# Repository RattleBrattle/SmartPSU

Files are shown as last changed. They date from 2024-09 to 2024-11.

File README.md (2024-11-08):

# SmartPSU

Welcome to the Smart Power Supply project! This repository contains the code and design files for a versatile power supply unit currently under development. The smart power supply is designed to provide reliable and adjustable power output for various applications, featuring multiple modes to cater to different power requirements.

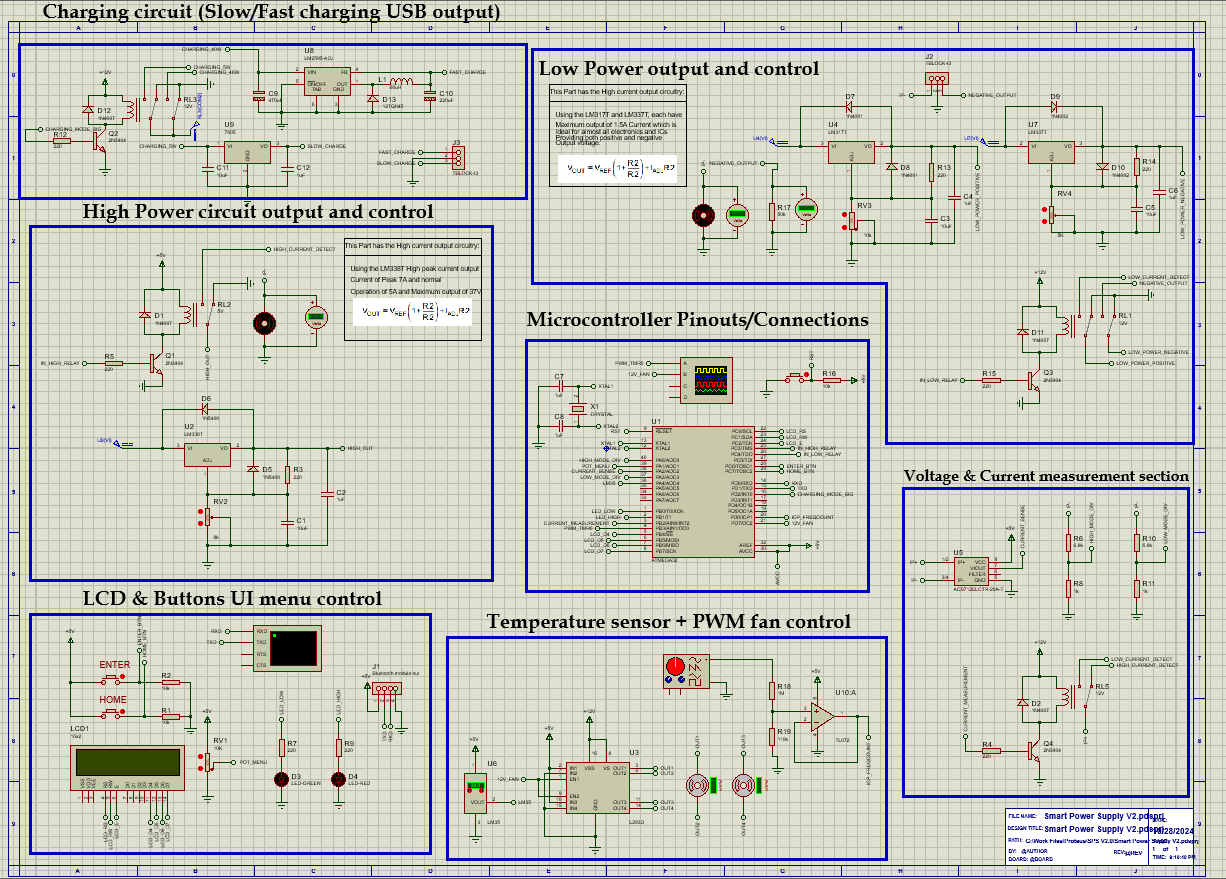
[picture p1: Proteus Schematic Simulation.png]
This Picture is a final representation of the Smart Power Supply circuit and is simulation for Proteus


## Features

The Smart Power Supply has 5 main features:
- The voltage is sensed using a voltage divider of Power Resistors.
- The Current is measured using the current sensor module board ACS712.

## Components:
* ACS712 Current sensor module board 20A.
* Linear Transformer 24V @ 5A.
* 4x 18650 battery holder.
* TP4056 Lithium battery charger.
* 120mm Fan.
* L7812, L7805 Regulators and their dependencies.
* LM317T and LM337T for Low power circuit and it's dependencies.
* LM338T for High Power circuit and it's dependencies.
* L293D for PWM fan control.
* LM35DZ Temperature sensor.
* LCD 16x2 display.
* 10kohm potentiometer, two buttons for the Menu controls.
* 2 USB type A female outputs for charging circuits output.
* 8 Banana Plugs for outputs of Power circuits and input of Frequency counter.

### High Power Mode:
- The mode's output is maximum at 5A, and at around 34V that means the output is around ~170W!
- Provides a high power output suitable for demanding applications and High Powered electronics.
- Ensures stable and efficient power delivery for high-performance devices using the effective but simple LM338T voltage regulator.

### Low Power Mode:
- This mode's output is maximum at 1.5, which is suitable for everyday electronics and logic circuits or weak motors.
- Offers a low power output for energy-efficient operation.
- Ideal for applications that require minimal power consumption.
- both positive and negative output using the LM317T and LM337T voltage regulators respectively.
- 
### Charging Circuits:
- 5W circuit and a 40W circuit for both USB output ports.
- Includes dedicated charging circuits for various battery types and Charging mobile phones.
- Supports charging for 18650 and Lithium-ion batteries.
- Ensures safe and efficient battery charging with built-in protection features.

40W Charging Circuit schematic:
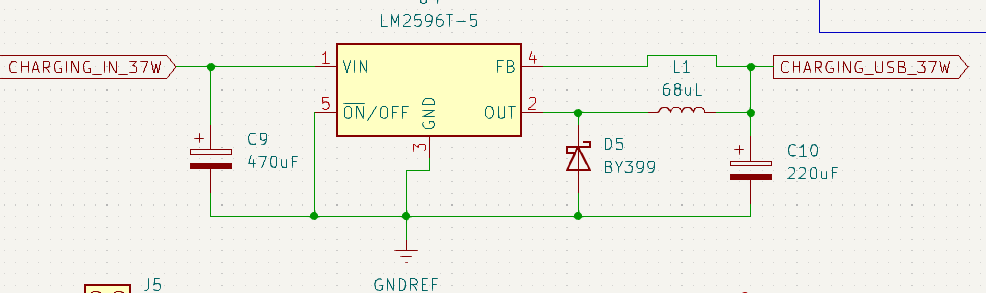
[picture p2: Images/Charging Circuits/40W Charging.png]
40W Charging Circuit


30W Charging Circuit schematic:
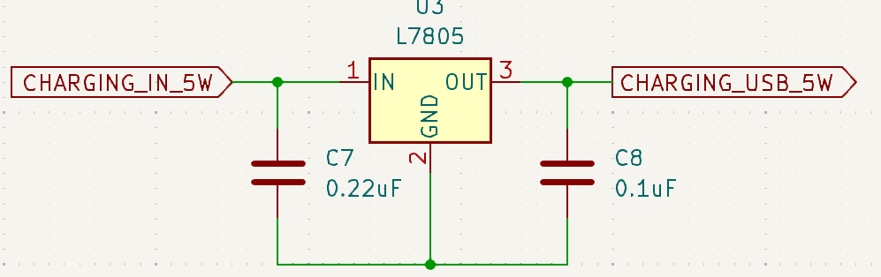
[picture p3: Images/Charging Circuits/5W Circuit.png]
30W Charging Circuit


### Frequency Counter:
- Using Precise calculations and the Timer 1 Peripheral on the ATmega32A, i managed to code a very useful feature
like that in the Smart Power Supply, simply put the frequency counter gives the user option to choose between the diverse
type of Prescalers in the ATmega32A Timer 1 peripheral depending on the frequency of the signal being tested.
The user Changes the Prescaler just like the main menu using the potentiometer and buttons.

- Example of the Menu:
Prescaler-Menu

### PWM Fan Control and Temperature sensor:
- The user can control the FAN speed by choosing the option in the Main Menu, using the L293D
as PWM controller and the Input power is 12V using the L7812 Regulator.
- The Power supply also has a critical function, a function that calculates the current temperature.
Where if the current temperature exceeds 35 degrees, Their is a warning message that is prompted to the user
on the LCD screen warning them!

The Temperature sensor and 12V fan Control:

## 3D Case model:
- I've modeled a 3D case for the Device using Fusion 360, the case is ready to be 3D printed as i've also uploaded the 3D files
above.

3D case Front:

3D case Back:

### Usage
When the user first powers on the device, the LCD screen prints out a menu with a cursor.
- The user controls the cursor position by moving the Main Menu potentiometer next to the LCD screen.
- When the user wants the function chosen, Press the "ENTR" button.
- When the user wants to exit the current function, Press the "HOME" button.

## Contributing

Contributions are welcome! If you have any suggestions, bug reports, or feature requests, Please email me at baselmohamed802@gmail.com or [message me on my LinkedIn page](www.linkedin.com/in/basel-sayed-b11534243) ! 

## License

This project is licensed under the [GNU] - see the [LICENSE](LICENSE) file for details.

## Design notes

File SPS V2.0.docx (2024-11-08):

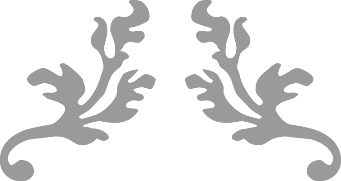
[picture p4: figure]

Smart power supply v2.0

A Smart power supply using ATmega32A Microcontroller capable of just about anything.

September 18, 2024

Basel Mohamed Mostafa Sayed

# SPS v2.0 details:

1) 120W+ Linear Power Supply.
2) Has two charging ports, one for normal speeds (5W) and the other for high-speed charging (37W).
- The 5W charging circuit will be current limited to 1A using the L7805 regulator.
- The 37W charging circuit will be using the LM2596 step-down voltage regulator.
3) Has two output voltage modes,
- The first is a positive only High ampere output capable of delivering full power at 7A peak.
- Using the LM338T voltage regulator
- The second is a positive AND negative medium (1.5A) output capable of everyday electronic testing.
- Using LM317T and LM337T for both positive and negative voltages respectively.
4) Has a charging port for 18650 batteries.
5) Has a charging port for Lithium-ion batteries using the TP4056 battery charging module.
6) PWM fan control using the L293D motor driver as PWM controller and Fan motor connection, and 12V regulator L7812 and IRF540N.

All of this will be controlled using the ATmega32A microcontroller.

- All the outputs will be controlled via relays or high power MOSFETS, each output will be a function that YOU (The user) execute via a menu that appears on the LCD.
- Voltage reading will be via voltage dividers.

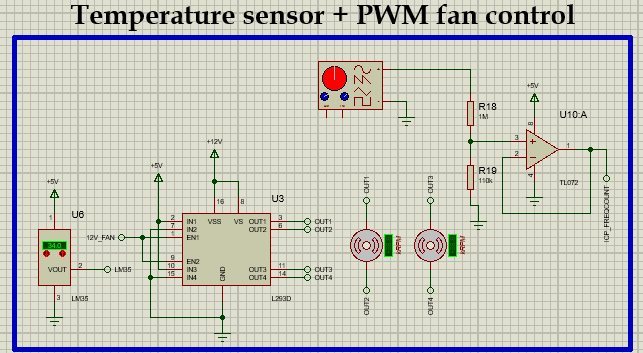
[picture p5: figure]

- Current reading will be using the ACS712 current sensor module (up to 20A).

## Explaining each function with detail:

In this section, I will explain to you each function that the SPS (Smart Power Supply) V2.0 is capable of and providing circuit schematic and connection explanations.

### 1) The main two outputs of the SPS v2.0:

→In here I will explain the main two outputs.

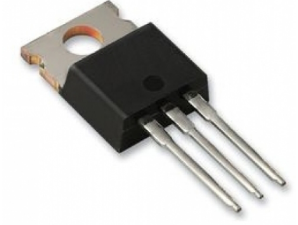
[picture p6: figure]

#### The first being the HIGH ampere output with full power.

→I will be using the LM338T, which is an excellent voltage regulator capable of delivering a MAX 5A load with 32V which will be more than enough to power most DC motors and high-powered components.

- Using the ATmega32’s PWM output (TMR0) as a driver for a MOSFET (NMOS) to efficiently and effectively control the output voltage.
- The MOSFET I am using is going to be IRLZ44N – NMOS, which for this use case is going to be more than sufficient in controlling the voltage output via PWM from the ATmega32A.

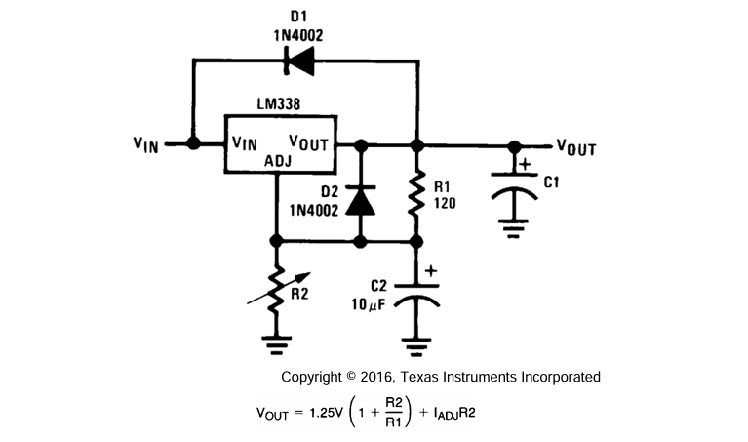
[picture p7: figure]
A diagram of a circuit

For the LM338T, we’re going to connect it using the figure given in the datasheet and since stated in the datasheet for outputs more than 24V we need protections diodes, so we’re going to use protection diodes.

For maximum output voltage which in the case of our smart power supply’s transformer

√2⋅24=33.9≈34V so, with this output in mind, we use the equation given by the datasheet to achieve maximum output.

34=1.25(1+(R_2)/220) So then R_2 =5984≈6kΩ .

So, for this configuration a variable resistor of 8K would do, but since there are no 8K potentiometer we can use the nearest value which would be 10K.

→Where the ATmega32A via user input using the menu on the LCD, sends a signal to the Relay controlling the output and sends it to the current sensor ACS712 and prints the voltage output and current measured on the LCD screen.

Here is the Final working simulation of the High-power output circuit:

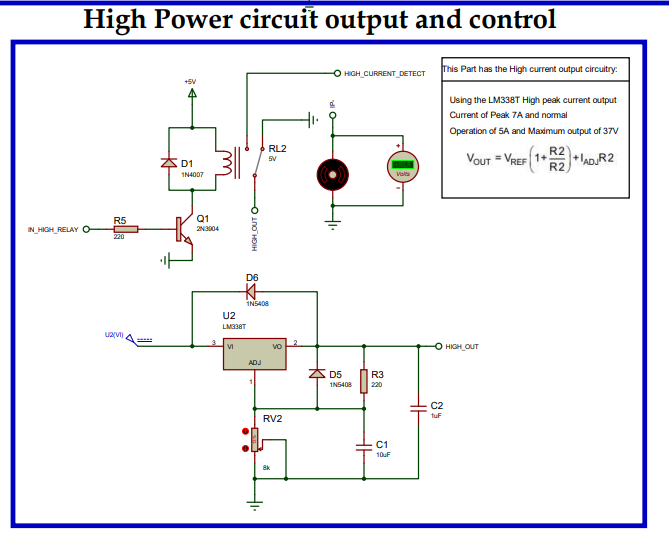
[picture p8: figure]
A diagram of a circuit
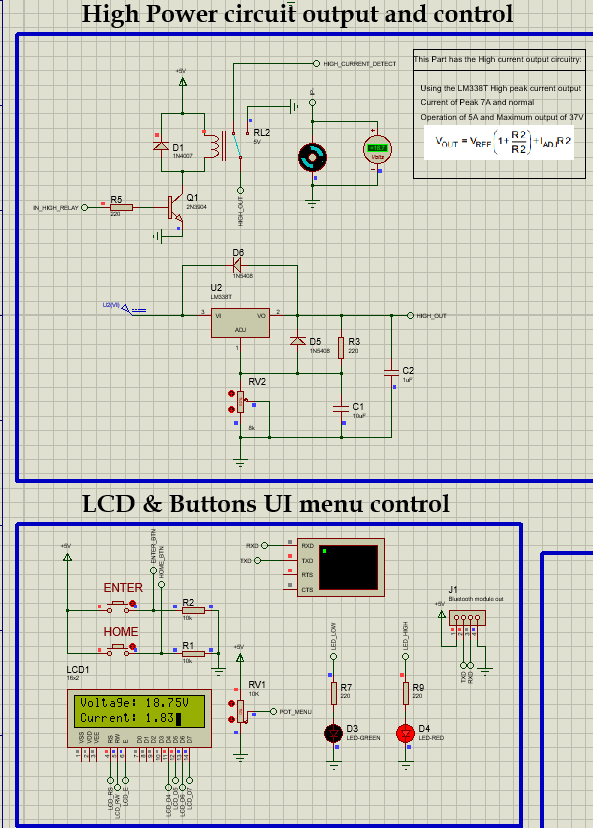
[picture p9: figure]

Here is the output voltage & current being measured by the ATmega32A and printed on the LCD screen:

#### The second being the Positive & Negative low output circuit:

→In this mode, I will stick to the tried and true positive and negative voltage regulators.

- The LM317T and the LM337T.
- Both offer the same Ampere output and will do greatly at just about testing everyday electronic components that don’t require much power unlike the LM338T.

Similarly, I am going to be using a PWM control signal to efficiently and effectively create a drive signal for the NMOS connected to the Low output.

Circuit for LM317T & LM337T:

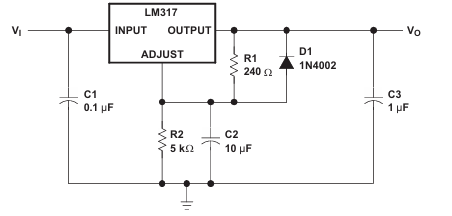
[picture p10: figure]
A diagram of a device

In this circuit, we have improved ripple rejection (increase signal output stability) by adding the capacitors at the input and C2 at the ADJ pin, similarly Diode D1 exists as protection in case the output is shorted to ground.

- The LM317T and LM337T follows the same formula as the LM338T so the circuit values are going to be the same as above and again, we will use the same 10K ohm potentiometer.

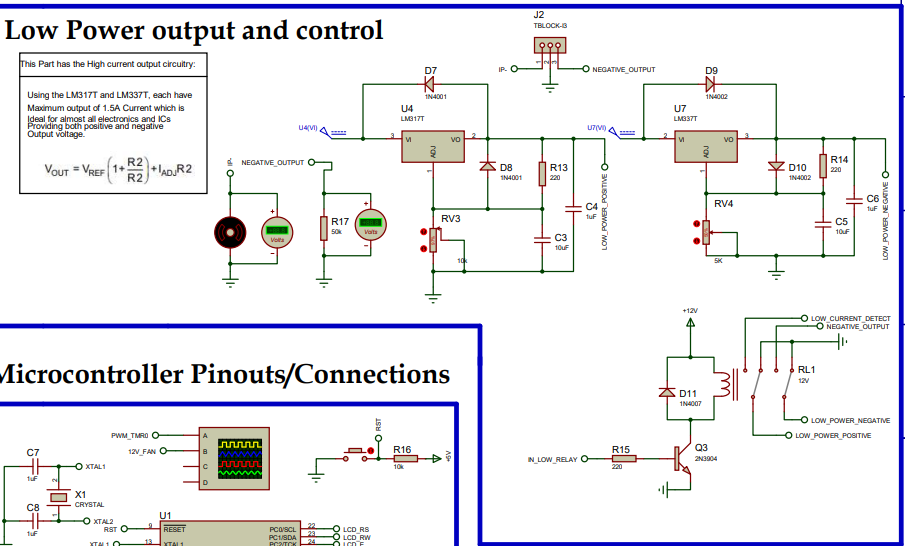
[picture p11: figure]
A diagram of a machine

→In the circuit above, we have the connections for the LM317T and LM337T with one signal that is controlled by the ATmega32A where once again like the High-power circuit, the voltage and current are measured and printed on the screen.

### 2) Charging circuits:

→The charging circuits for the USB output ports are simple enough to charge most phones and power most USB powered electronic devices.

To enable the Charging circuit outputs, the user chooses mode 3 in the LCD screen menu which sends a signal via the ATmega32A to the Relay controlling the Charging circuits and also sends power to the Lithium Battery Charger and 18650 Battery charger.

#### Slow Charging circuit:

- The 5W-7.5W circuit is meant to be used to power low power electronics via USB output or charge old phones, and smartwatches.

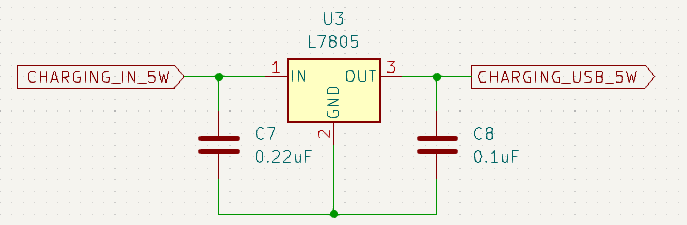
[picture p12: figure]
A diagram of a circuit

- The Circuit is going to be built using the simple regulator L7805, where 5V is the target output voltage.

#### Fast Charging circuit:

- This circuit is going to use the LM2596 – ADJ regulator.

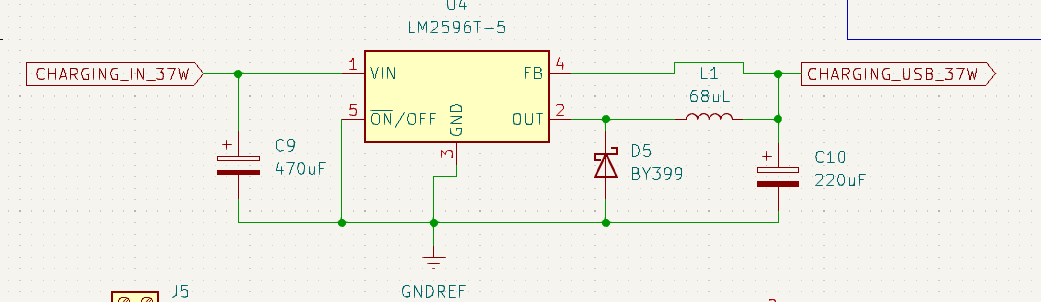
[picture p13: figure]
A diagram of a circuit

All the values are chosen according to the datasheet to provide the highest stable output voltage with low voltage ripple.

#### TP4056 Lithium battery charger:

→There is another output charging signal that is sent by the ATmega32A controller when the user chooses Charging mode, that activates the Lithium Battery Charger and the 18650-battery charging.

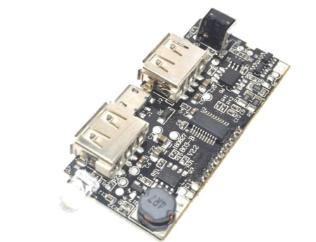
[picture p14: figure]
A close-up of a circuit board
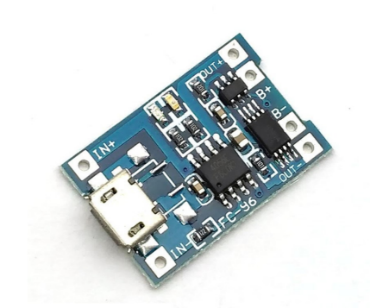
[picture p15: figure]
A close-up of a circuit board

1) TP4056 module.
2) Using a 15W battery bank charger module to charge the 18650 batteries.

→I have decided to exclude this mode for the time being just because there is no simulation for them in proteus but in real life it could be easily added and in fact, already coded into the ATmega32A.

### 3) Frequency Counter:

The Frequency Counter is implemented using the Timer 1 “Input Capture Unit” in the ATmega32A by setting the appropriate mode and using the Timer 1 driver, I achieved a 0-50V input range and maximum of 1MHZ frequency that could be read.

- This mode also gives the user complete access to choose and change the Prescaler to be used by the Timer 1, which gives the user much more control over the mode and allows for a very diverse and wide selection of signals to be read.

By choosing this mode, the user is prompted with a menu to choose the Prescaler to use:

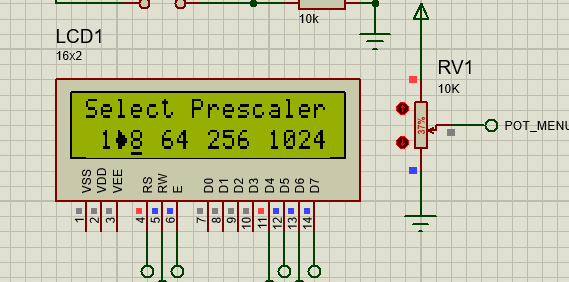
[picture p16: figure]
A screenshot of a computer

- By moving the potentiometer, the user can change the Arrow cursor.

## Smart Power Supply case design using Fusion 360:

→I also modeled a 3D printable case for the PSU using fusion 360.

- The case houses all the internal components for the Smart Power Supply and the appropriate cut-outs for the LCD screen, menu buttons and whatnot.

External Case front face and side, showing the menu buttons, LCD screen and output banana plugs with the top having a 120mm fan mounted and to the side we have battery 18650 charging:

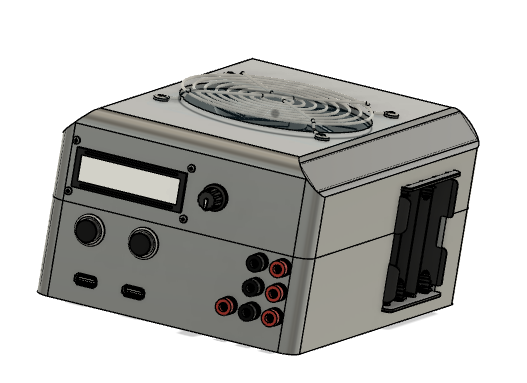
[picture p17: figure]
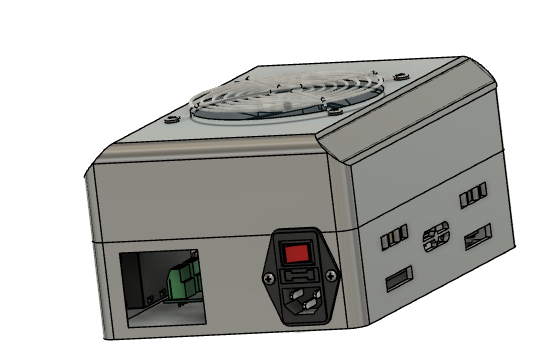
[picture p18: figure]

Where in the back we have the Power AC input with fuse and switch mount and we also have a cut hole for ventilation and in the other side, we have more ventilation holes.

Smart power supply v2.0 2

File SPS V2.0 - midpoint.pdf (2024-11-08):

# SMART POWER SUPPLY V2.0

## A Smart power supply using ATmega32A Microcontroller capable of just about

anything.

## SEPTEMBER 18, 2024

BASEL MOHAMED MOSTAFA SAYED

SPS V2.0 DETAILS:

1) 120W+ Linear Power Supply.
2) Has two charging ports, one for normal speeds (5W) and the other for high-speed charging (37W).
- The 5W charging circuit will be current limited at 1A using the L7805 regulator.
- The 37W charging circuit will be using the L7818 Regulator.
3) Has two output voltage modes,
➔ The first is a positive only High ampere output capable of delivering full power (120W)
- Using the LM338T voltage regulator
➔ The second is a positive AND negative medium (1.5A) output capable of everyday electronic testing.
- Using LM317T and LM337T for both positive and negative voltages respectively.
4) Has a charging port for 18650 batteries.
5) Has a charging port for Lithium-ion batteries using the TP4056 battery charging module.

All of this will be controlled using the ATmega32A microcontroller.

➔ All the outputs will be controlled via relays or high power MOSFETS, each output will be a function that YOU (The user) execute via a menu that appears on the LCD.
➔ Voltage reading will be via voltage dividers.
➔ Current reading will be using the ACS712 current sensor module (up to 20A).

There are currently 3 working modes in the SPS project but in the future, I want to add at least two more useful modes like a built in Function generator and a Frequency counter using Timer 1 peripheral.

I’ve also created a GitHub page that is still in the works that explains the project a bit more, over at the link below.

➔ https://github.com/RattleBrattle/SmartPSU.git

EXPLAINING EACH FUNCTION WITH DETAIL:

In this section, I will explain to you each function that the SPS (Smart Power Supply) V2.0 is capable of and providing circuit schematic and connection explanations.

1) THE MAIN TWO OUTPUTS OF THE SPS V2.0:
→In here I will explain the main two outputs.

THE FIRST BEING THE HIGH AMPERE OUTPUT WITH FULL POWER.

→I will be using the LM338T, which is an excellent voltage regulator capable of delivering a MAX 5A load with 32V which will be more than enough to power most DC motors and high-powered components.

- Using the ATmega32’s PWM output (TMR0) as a driver for a MOSFET (NMOS) to efficiently and effectively control the output voltage.
- The MOSFET I am using is going to be IRLZ44N – NMOS, which for this use case is going to be more than sufficient in controlling the voltage output via PWM from the ATmega32A.

For the LM338T, we’re going to
connect it using the figure given in the datasheet and since stated in the datasheet for outputs more than 24V we need protections diodes, so we’re going to use protection diodes.

Since I’m going to control the output voltage using the
NMOSFET instead, so I am going to R2 to the highest value possible.

34 = 1.25 (1 +

R2

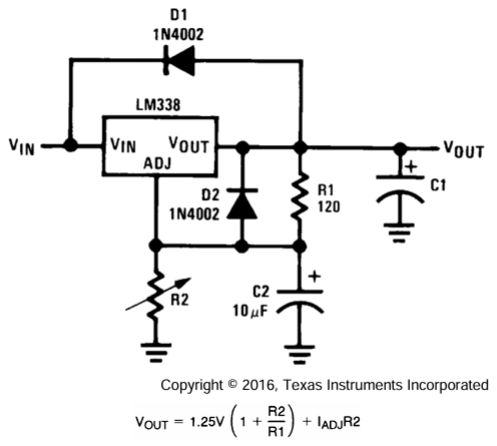
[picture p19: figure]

220) So then R2 = 5984 ≈ 6kΩ.

So, for this configuration a resistor of 6K would do.

THE SECOND BEING THE LOW AMPERE OUTPUT WITH MINIMUM POWER.

→In this mode, I will stick to the tried and true positive and negative voltage regulators.

- The LM317T and the LM337T.
- Both offer the same Ampere output and will do greatly at just about testing everyday electronic components that don’t require much power unlike the LM338T.

Similarly, I am going to be using a PWM control signal to efficiently and effectively create a drive signal for the NMOS connected to the Low output.

Circuit for LM317T:

In this circuit, we have
improved ripple rejection
(increase signal output
stability) by adding the
capacitors at the input and C2 at the ADJ pin, similarly Diode D1 exists as
protection in case the
output is shorted to ground.
- The LM317T
follows the same

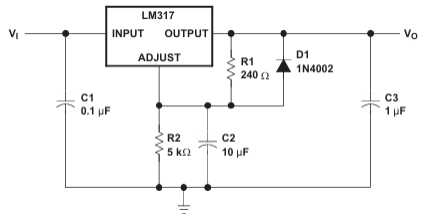
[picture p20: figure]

formula as the LM338T so the circuit values are going to be the same as above.

2) CHARGING CIRCUITS:
→The charging circuits for the USB output ports are simple enough to charge most phones and power most USB powered electronic devices.

To enable the Charging circuit outputs, the user chooses mode 3 in the LCD screen menu which sends a signal via the ATmega32A to the Relay controlling the Charging circuits and also sends power to the Lithium Battery Charger and 18650 Battery charger.

5W CHARGING CIRCUIT:
➔ The 5W-7.5W circuit is meant to be used to power low power electronics via USB output or charge old phones, and smartwatches.
➔ The Circuit is going to be built using the simple regulator L7805, where 5V is the target output voltage.

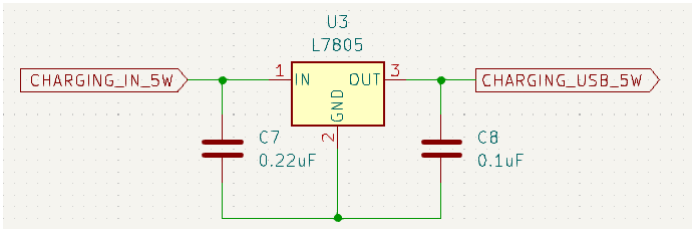
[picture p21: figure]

15W CHARGING CIRCUIT:
➔ This circuit is going to use the LM2596 – 5V regulator.

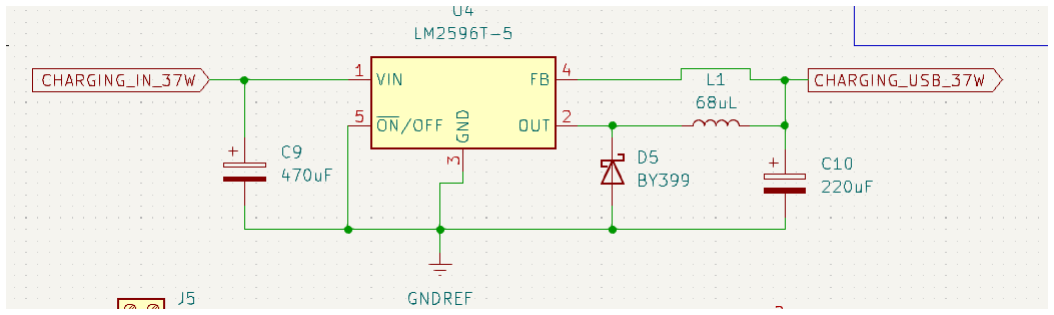
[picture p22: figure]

All the values are chosen according to the datasheet to provide the highest stable output voltage with low voltage ripple.

TP4056 LITHIUM BATTERY CHARGER:
→There is another output charging signal that is sent by the ATmega32A controller when the user chooses Charging mode, that activates the Lithium Battery Charger and the 18650 battery charging.

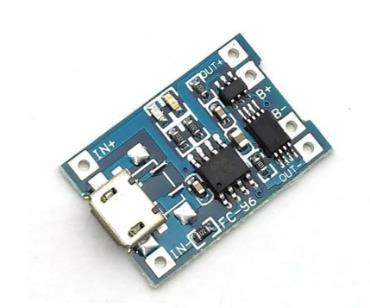
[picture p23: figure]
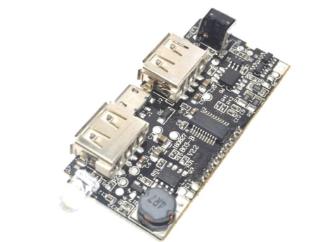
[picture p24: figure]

1) TP4056 module.
2) Using a 15W battery bank charger module to charge the 18650 batteries.
3) FREQUENCY COUNTER:
→WIP!

4)FUNCTION GENERATOR:
→Using the inbuilt PWM signal for Timer 2 peripheral and op-amps.

→WIP!

SMART POWER SUPPLY CASE DESIGN:

→WIP!

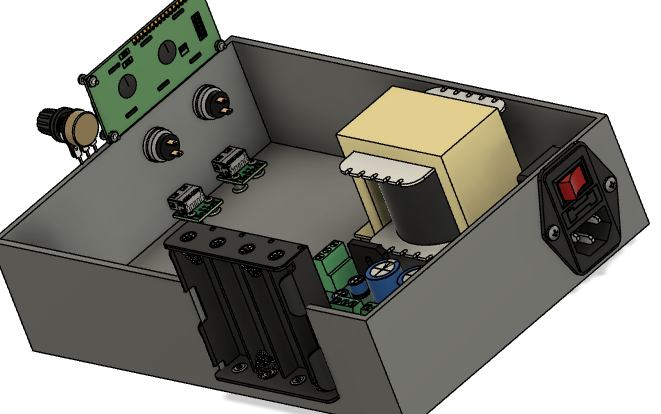
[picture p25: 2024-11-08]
3D Case/Pictures/Case design mid-way.png

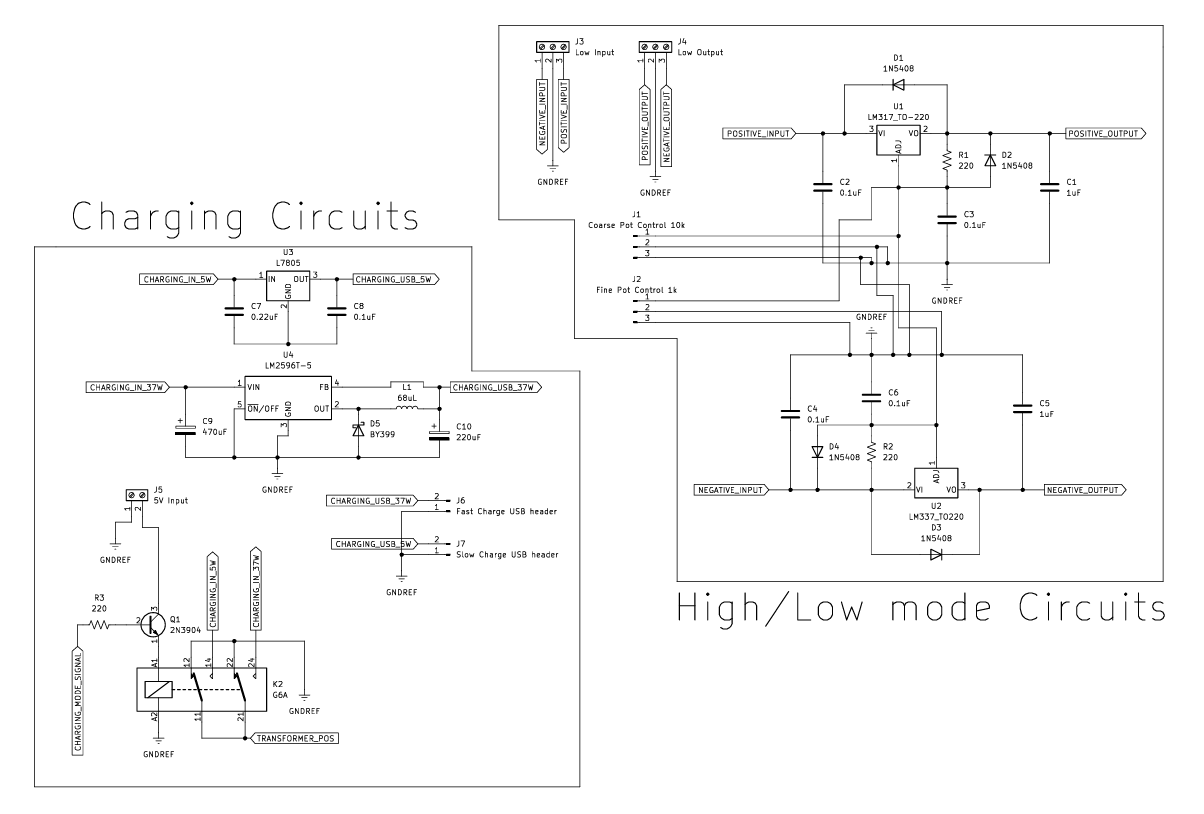
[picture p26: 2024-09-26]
Power & Charging Schematic - midpoint.png

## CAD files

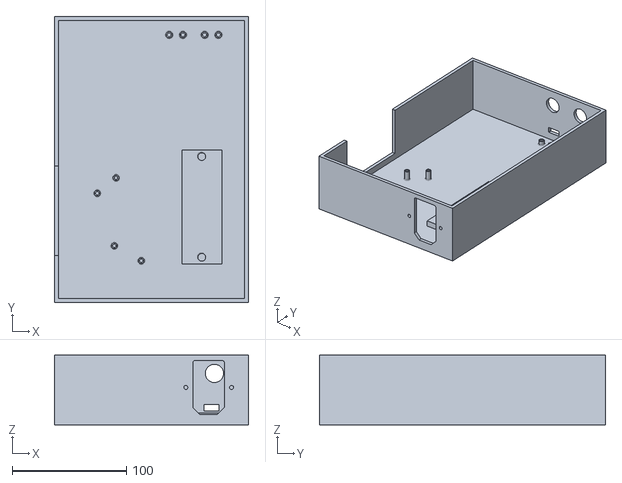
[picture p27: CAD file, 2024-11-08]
3D Case/STL/Bottom Case V12.stl
170.0 x 250.0 x 61.0

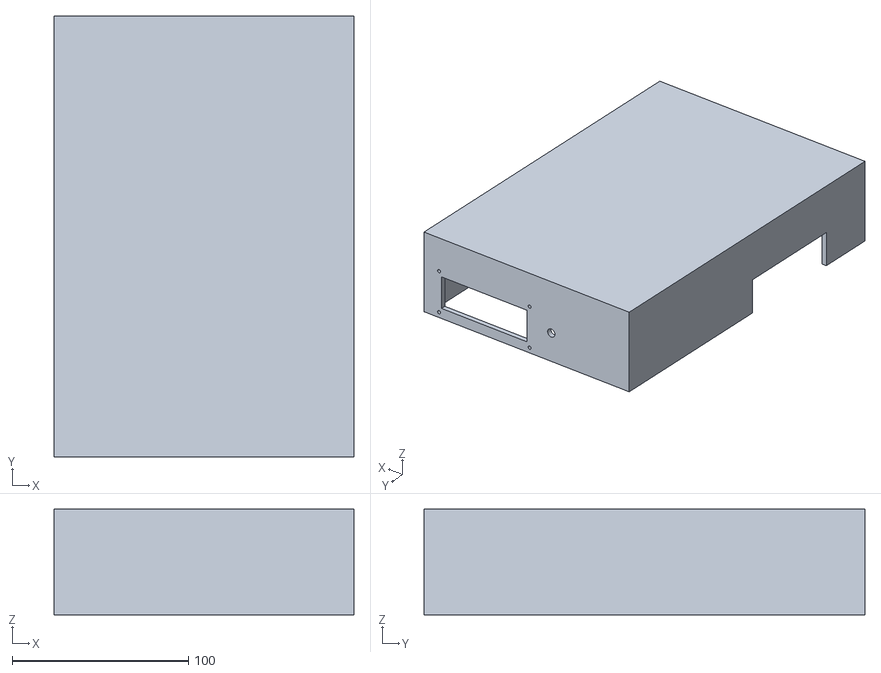
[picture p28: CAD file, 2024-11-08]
3D Case/STL/Top Case - V12.stl
170.0 x 250.0 x 60.0

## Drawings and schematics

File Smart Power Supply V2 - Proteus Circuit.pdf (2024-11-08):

RL3

Q2

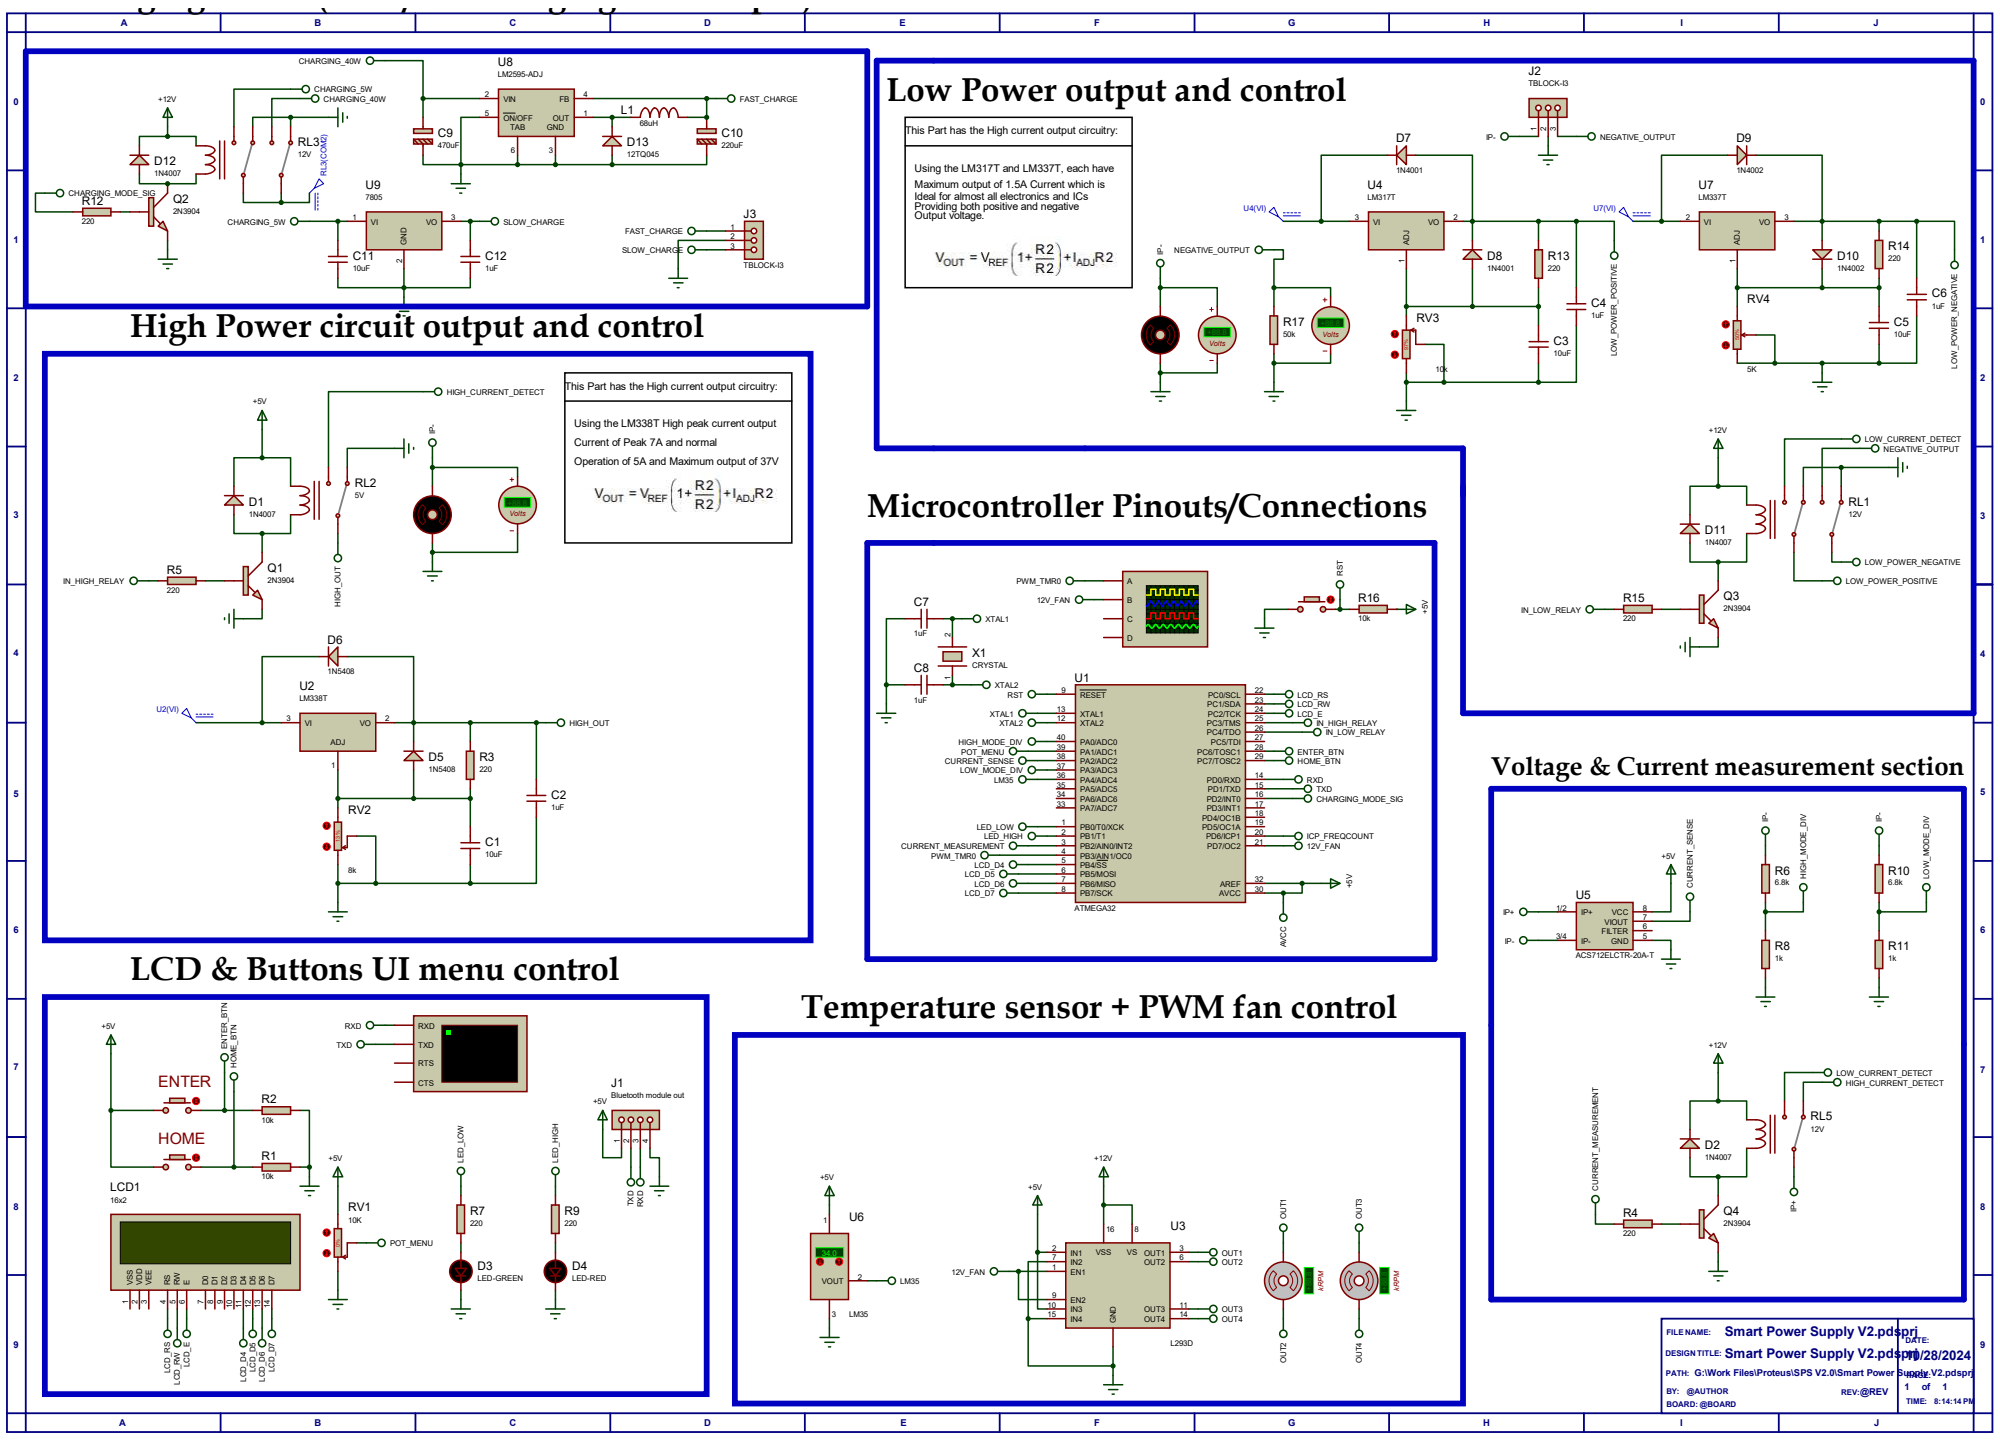
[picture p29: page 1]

Low Power output and control

This Part has the High current output circuitry:

Using the LM317T and LM337T, each have
Maximum output of 1.5A Current which is
Ideal for almost all electronics and ICs
Providing both positive and negative
Output voltage.

High Power circuit output and control

Using the LM338T High peak current output
Current of Peak 7A and normal
Operation of 5A and Maximum output of 37V

Voltage & Current measurement section

ATMEGA32 D⁷ 14 D⁶ 13 D⁵ 12 D⁴ 11 D³ 10 D²
LCD & Buttons UI menu control
10k ENTER_BTN HOME_BTN

Temperature sensor + PWM fan control

FILE NAME:
DESIGN TITLE: Smart Power Supply V2.pdsprj

Smart Power Supply V2.pdsprj

PATH: G:\Work Files\Proteus\SPS V2.0\Smart Power Supply V2.pdsprj

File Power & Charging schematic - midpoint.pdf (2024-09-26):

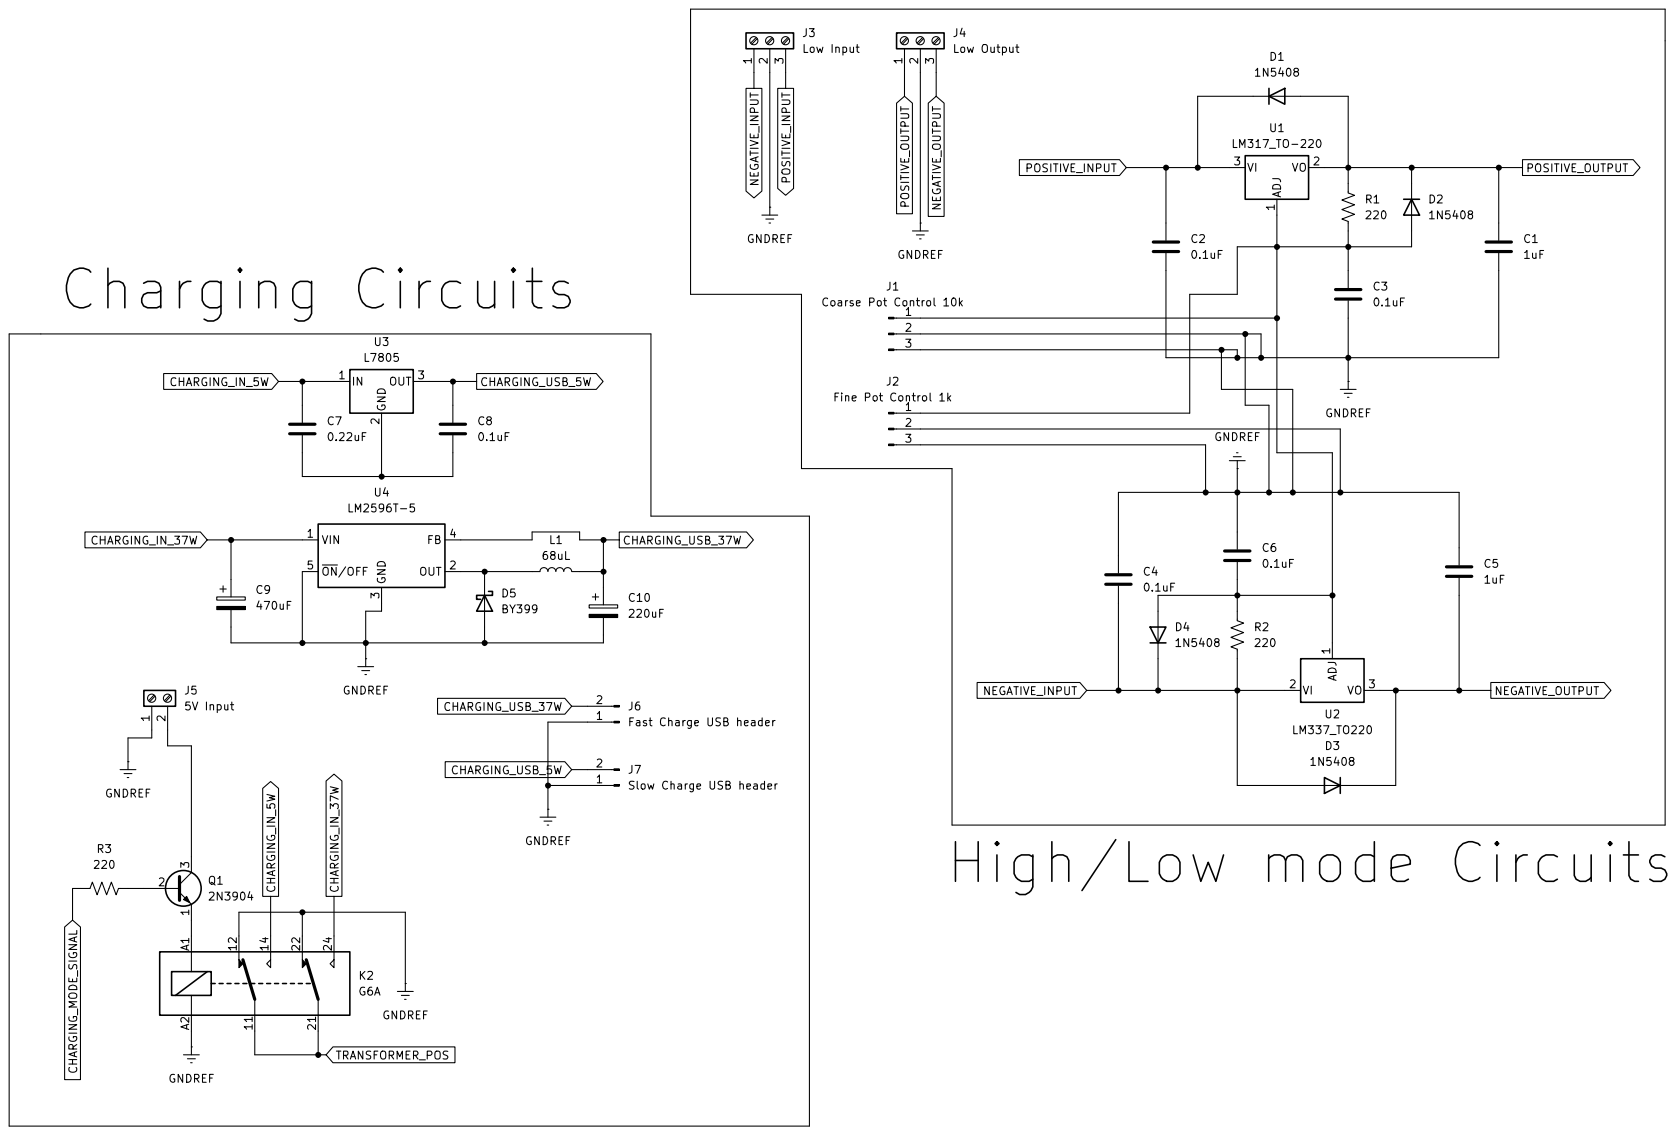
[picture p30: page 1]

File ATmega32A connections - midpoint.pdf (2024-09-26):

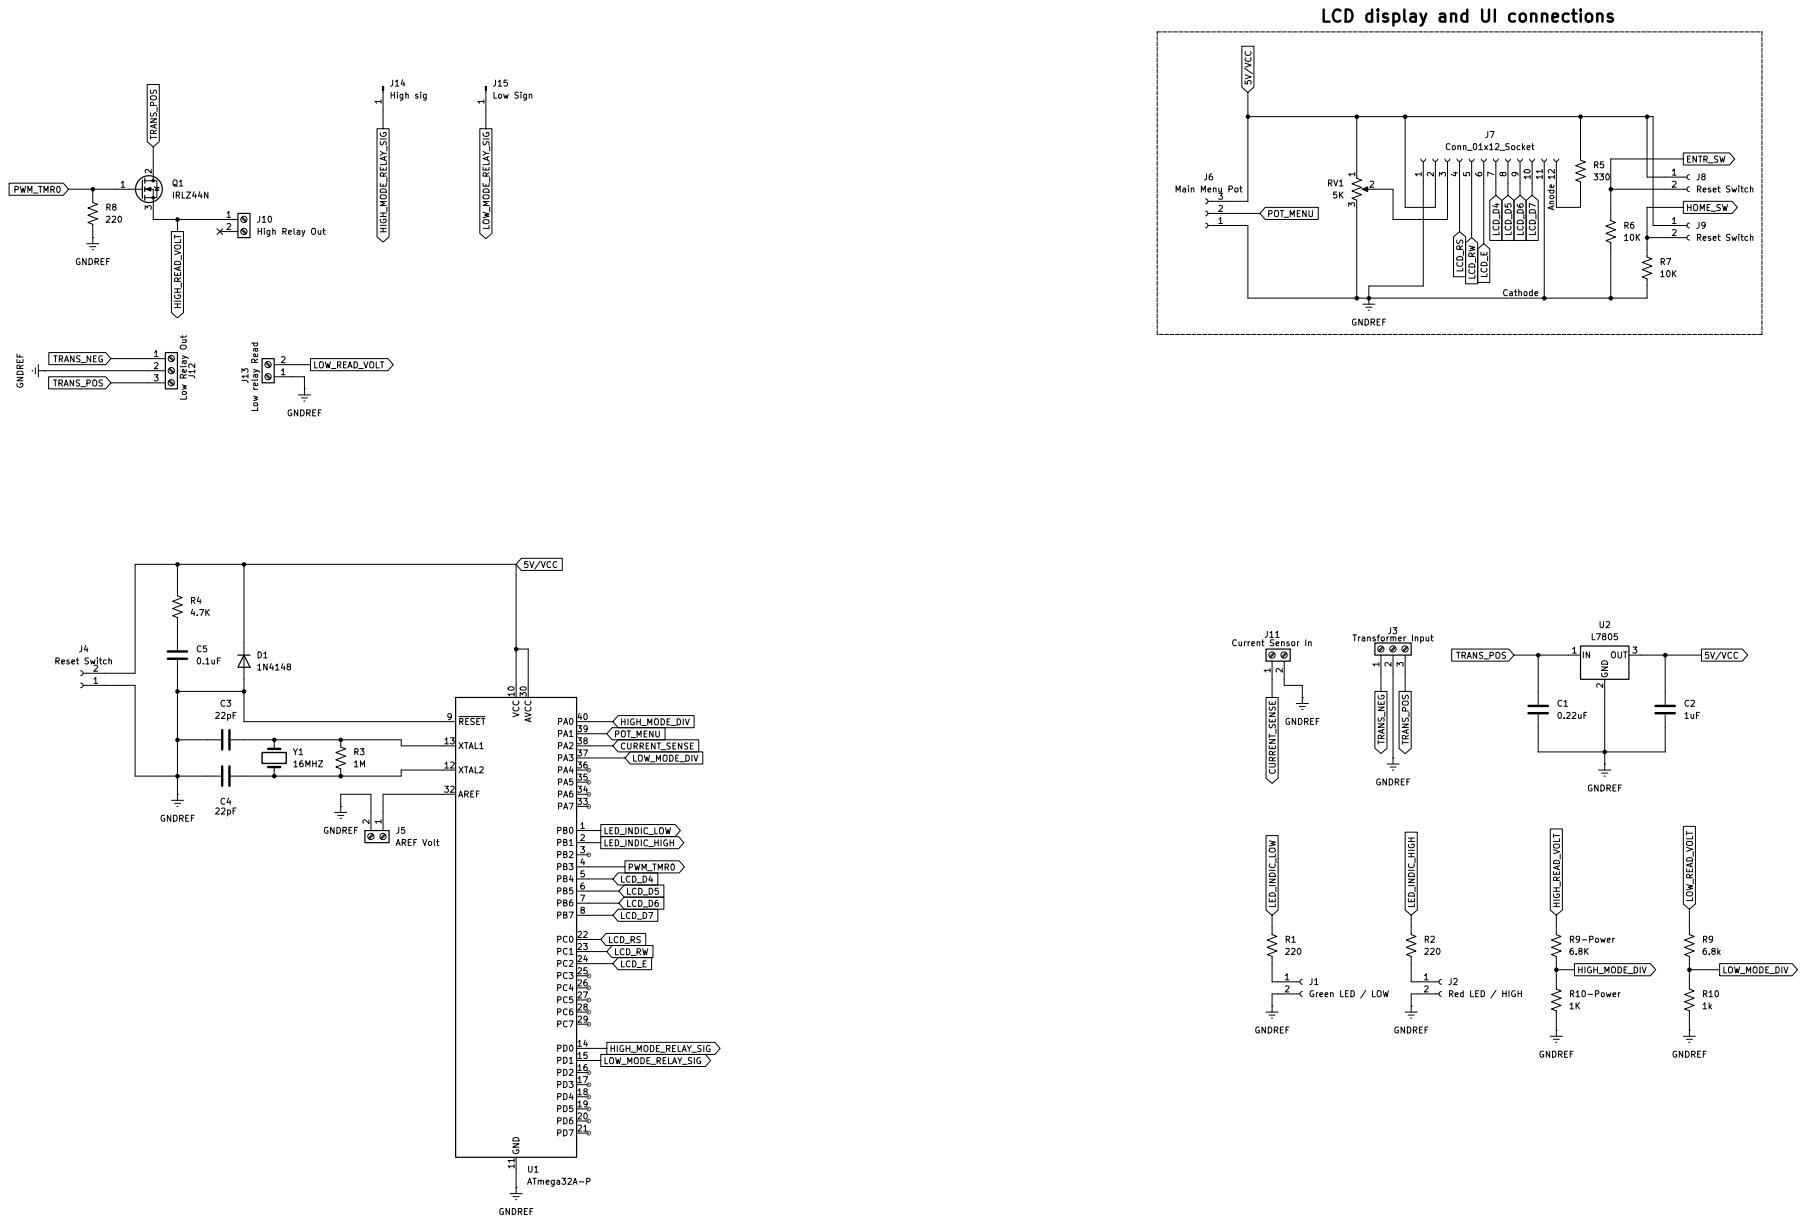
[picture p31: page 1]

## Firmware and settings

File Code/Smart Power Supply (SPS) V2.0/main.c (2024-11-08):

/*
 * Smart Power Supply (SPS) V2.0.c
 * Created: 9/17/2024 8:43:58 PM
 *
 * Author: Basel Mohamed Mostafa Sayed
 * Email: baselmohamed802@gmail.com
 * LinkedIn: www.linkedin.com/in/basel-sayed-b11534243
 * Phone: 01033453452
 *
 * Description:
 * This main.c file contains the code for the Smart power supply V2.0.
 * The Smart Power Supply is a 120W power supply with many functionalities like
 * High Volt/Amp output, and Low Volt/Amp output. It also has Automatic overheat
 * shutdown detection using the LM35 temperature sensor. The main future of the
 * Power Supply is that everything is controlled via a menu using the LCD 16x2
 * and a simple potentiometer.
 */

#define F_CPU 16000000UL

/* UTILS */
#include "UTILS/Bit_operation.h"
#include "UTILS/STD_TYPES.h"
#include "UTILS/VECTOR.h"

/* MCAL */
#include <util/delay.h>

#include "../../../MCAL/ADC_DRIVER/ADC_DRIVER/ADC_PROGRAM.c"
#include "../../../MCAL/ADC_DRIVER/ADC_DRIVER/ADC_PROGRAM.h"
#include "../../../MCAL/ADC_DRIVER/ADC_DRIVER/ADC_REG.h"
#include "../../../MCAL/GIE_DRIVER/GIE_DRIVER/GIE_PROGRAM.c"
#include "../../../MCAL/GIE_DRIVER/GIE_DRIVER/GIE_PROGRAM.h"
#include "../../../MCAL/GIE_DRIVER/GIE_DRIVER/GIE_REG.h"
#include "../../../MCAL/TIMER/TMR0_INTERRUPT/TIMER_INTERRUPT/TMR0_CONFIG.h"
#include "../../../MCAL/TIMER/TMR0_INTERRUPT/TIMER_INTERRUPT/TMR0_PRIVATE.h"
#include "../../../MCAL/TIMER/TMR0_INTERRUPT/TIMER_INTERRUPT/TMR0_PROGRAM.c"
#include "../../../MCAL/TIMER/TMR0_INTERRUPT/TIMER_INTERRUPT/TMR0_PROGRAM.h"
#include "../../../MCAL/TIMER/TMR0_INTERRUPT/TIMER_INTERRUPT/TMR0_REG.h"
#include "../../../MCAL/TIMER/TMR1_INTERRUPT/TMR1_INTERRUPT/TMR1_CONFIG.h"
#include "../../../MCAL/TIMER/TMR1_INTERRUPT/TMR1_INTERRUPT/TMR1_PROGRAM.c"
#include "../../../MCAL/TIMER/TMR1_INTERRUPT/TMR1_INTERRUPT/TMR1_PROGRAM.h"
#include "../../../MCAL/TIMER/TMR1_INTERRUPT/TMR1_INTERRUPT/TMR1_REG.h"
#include "../../../MCAL/TIMER/TMR2_INTERRUPT/TMR2_INTERRUPT/TMR2_CONFIG.h"
#include "../../../MCAL/TIMER/TMR2_INTERRUPT/TMR2_INTERRUPT/TMR2_PROGRAM.h"
#include "../../../MCAL/TIMER/TMR2_INTERRUPT/TMR2_INTERRUPT/TMR2_PROGRAM.c"
#include "../../../MCAL/TIMER/TMR2_INTERRUPT/TMR2_INTERRUPT/TMR2_REG.h"
#include "ATmega32_DIO/DIO_PROGRAM.h"
#include "ATmega32_DIO/DIO_REG.h"

/* HAL */
#include "../../../HAL/LCD_DRIVER/LCD_DRIVER/LCD_AMIT_KIT_CONFIG.h"
#include "../../../HAL/LCD_DRIVER/LCD_DRIVER/LCD_PROGRAM.c"
#include "../../../HAL/LCD_DRIVER/LCD_DRIVER/LCD_PROGRAM.h"
#include "../../../HAL/LM35 - Temp Sensor/LM35 - Temp Sensor/LM35_PROGRAM.c"
#include "../../../HAL/LM35 - Temp Sensor/LM35 - Temp Sensor/LM35_PROGRAM.h"
#include "../../../HAL/SWITCH_DRIVER/SWITCH_DRIVER/SWITCH_PROGRAM.c"
#include "../../../HAL/SWITCH_DRIVER/SWITCH_DRIVER/SWITCH_PROGRAM.h"
#include "SPSV2_PROGRAM.h"

// Custom character for the cursor to display on screen
u8 arrowCursor[] = {0b01000, 0b01100, 0b01110, 0b11111,
                    0b11111, 0b01110, 0b01100, 0b01000};

int main(void) {
   // function to initialize all pins connected
   SPSV2_init();

   // Initializing All the HAL/MCAL components connected
   GIE_enable();
   LCD_init();
   ADC_init(ADC_REFERENCE_AVCC);
   TMR0_init(TMR0_FASTPWM_MODE, TMR0_PRELOAD_CLR, TMR0_PWM_NON_INVERT);

   // Calling the Start up function once
   SPSV2_startProg();

   // Defining variables
   u8 local_u8CurrentCursorPos = 0, local_u8CurrentScreenPos = 0;

   while (1) {
      // Read ADC value from channel 1
      u16 local_u16AdcValue = ADC_getValue(ADC_CHANNEL1);

      // Read Temperature
      SPSV2_readTemp();

      // Calling the function to update the screen and cursor position
      SPSV2_updateScreenPosition(local_u16AdcValue, &local_u8CurrentCursorPos,
                                 &local_u8CurrentScreenPos);

      // Calling the Print menu function
      SPSV2_printMenu(local_u8CurrentCursorPos, local_u8CurrentScreenPos);
      LCD_createAndDisplayChar(0, arrowCursor, local_u8CurrentCursorPos, 0);

      // Calling the function to choose which operation to initiate
      SPSV2_chooseFun(local_u8CurrentCursorPos, local_u8CurrentScreenPos);

      _delay_ms(200);
   }

   return 0;
}

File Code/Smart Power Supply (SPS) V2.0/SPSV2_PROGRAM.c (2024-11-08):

/*
 *SPSV2_PROGRAM.c
 *
 *Created: 9/17/2024 8:49:37 PM
 *Author: Basel Mohamed Mostafa Sayed
 *Description: This file contains all the source code for the functions used in
 *the Smart Power Supply V2.0 system
 */
#define F_CPU 16000000UL

/*UTILS */
#include "UTILS/Bit_operation.h"
#include "UTILS/STD_TYPES.h"
#include "UTILS/VECTOR.h"

/*MCAL */
#include <util/delay.h>

#include "../../../MCAL/ADC_DRIVER/ADC_DRIVER/ADC_PROGRAM.h"
#include "../../../MCAL/ADC_DRIVER/ADC_DRIVER/ADC_REG.h"
#include "../../../MCAL/GIE_DRIVER/GIE_DRIVER/GIE_PROGRAM.h"
#include "../../../MCAL/GIE_DRIVER/GIE_DRIVER/GIE_REG.h"
#include "../../../MCAL/TIMER/TMR0_INTERRUPT/TIMER_INTERRUPT/TMR0_CONFIG.h"
#include "../../../MCAL/TIMER/TMR0_INTERRUPT/TIMER_INTERRUPT/TMR0_PROGRAM.h"
#include "../../../MCAL/TIMER/TMR0_INTERRUPT/TIMER_INTERRUPT/TMR0_REG.h"
#include "../../../MCAL/TIMER/TMR1_INTERRUPT/TMR1_INTERRUPT/TMR1_CONFIG.h"
#include "../../../MCAL/TIMER/TMR1_INTERRUPT/TMR1_INTERRUPT/TMR1_PROGRAM.h"
#include "../../../MCAL/TIMER/TMR1_INTERRUPT/TMR1_INTERRUPT/TMR1_REG.h"
#include "../../../MCAL/TIMER/TMR2_INTERRUPT/TMR2_INTERRUPT/TMR2_CONFIG.h"
#include "../../../MCAL/TIMER/TMR2_INTERRUPT/TMR2_INTERRUPT/TMR2_PROGRAM.h"
#include "../../../MCAL/TIMER/TMR2_INTERRUPT/TMR2_INTERRUPT/TMR2_REG.h"
#include "ATmega32_DIO/DIO_PROGRAM.h"
#include "ATmega32_DIO/DIO_REG.h"

/*HAL */
#include "../../../HAL/LCD_DRIVER/LCD_DRIVER/LCD_AMIT_KIT_CONFIG.h"
#include "../../../HAL/LCD_DRIVER/LCD_DRIVER/LCD_PRIVATE.h"
#include "../../../HAL/LCD_DRIVER/LCD_DRIVER/LCD_PROGRAM.h"
#include "../../../HAL/LM35 - Temp Sensor/LM35 - Temp Sensor/LM35_PROGRAM.h"
#include "../../../HAL/SWITCH_DRIVER/SWITCH_DRIVER/SWITCH_PROGRAM.h"
#include "SPSV2_PROGRAM.h"

u8 arrowCursor2[] = {0b01000, 0b01100, 0b01110, 0b11111,
                     0b11111, 0b01110, 0b01100, 0b01000};

void SPSV2_init(void) {
   /*Initializing important pin directions */
   DIO_setPinDirection(MAIN_MENU_POT_PORT, MAIN_MENU_POT_PIN,
                       DIO_PIN_INPUT);  // Potentiometer Pin input ADC
   DIO_setPinDirection(VOLT_DIV_HIGH_PORT, VOLT_DIV_HIGH_PIN,
                       DIO_PIN_INPUT);  // High mode Voltage Divider pin
   DIO_setPinDirection(VOLT_DIV_LOW_PORT, VOLT_DIV_LOW_PIN, DIO_PIN_INPUT); // Low mode voltage Divider pin
   DIO_setPinDirection(
       ACS712_PORT, ACS712_PIN,
       DIO_PIN_OUTPUT);  // Current measurement module for Low/High outputs pin
   DIO_setPinDirection(PWM0_PORT, PWM0_PIN,
                       DIO_PIN_OUTPUT);               // PWM on Timer 0 pin
   SWITCH_init(ENTER_SWITCH_PORT, ENTER_SWITCH_PIN);  // Enter switch Pin
   SWITCH_init(HOME_SWITCH_PORT, HOME_SWITCH_PIN);    // Home switch Pin
   DIO_setPinDirection(
       RELAY_HIGH_OUT_PORT, RELAY_HIGH_OUT_PIN,
       DIO_PIN_OUTPUT);  // Relay control Pin for the High power output
   DIO_setPinDirection(
       RELAY_LOW_OUT_PORT, RELAY_LOW_OUT_PIN,
       DIO_PIN_OUTPUT);  // Relay control Pin for the low power output
   DIO_setPinDirection(LED_INDIC_HIGH_PORT, LED_INDIC_HIGH_PIN,
                       DIO_PIN_OUTPUT);  // LED indicator pin for High output
   DIO_setPinDirection(LED_INDIC_LOW_PORT, LED_INDIC_LOW_PIN,
                       DIO_PIN_OUTPUT);  // LED indicator pin for low output
   DIO_setPinDirection(CHARGE_MODE_SIG_PORT, CHARGE_MODE_SIG_PIN,
                       DIO_PIN_OUTPUT);  // Charging mode activate signal
   DIO_setPinDirection(LM35_PORT, LM35_PIN,
                       DIO_PIN_INPUT);  // Temperature sensor pin (LM35)
   DIO_setPinDirection(ACS712_MEASUREMENT_PORT, ACS712_MEASUREMENT_PIN,
                       DIO_PIN_OUTPUT);  // Current measurement relay signal
   DIO_setPinDirection(FAN_PORT, FAN_PIN, DIO_PIN_OUTPUT); // 12V Fan header pin
}

void SPSV2_startProg(void) {
   // Printing on the LCD details about the program
   LCD_displayString((u8 *)"SPS V2");
   LCD_moveCursor(1, 0);
   LCD_displayString((u8 *)"Initializing .");
   _delay_ms(500);
   LCD_displayString((u8 *)".");
   _delay_ms(500);
   LCD_displayString((u8 *)".");
}

void SPSV2_readTemp(void) {
   u8 local_u8Err = 0;
   f32 local_u16Temp = LM35_getVal(ADC_CHANNEL4);

   // if the temperature exceeds 35 degree Celsius, the program prompts the user
   // with a warning to turn off the SPSU
   if (local_u16Temp > 35.0) {
      LCD_clear();
      LCD_displayString((u8 *)"Warning");
      _delay_ms(250);
      LCD_displayChar('!');
      _delay_ms(250);
      LCD_displayChar('!');
      _delay_ms(250);
      LCD_clear();
      LCD_displayString((u8 *)"Temperature is");
      LCD_moveCursor(1, 0);
      LCD_displayString((u8 *)"Too hot!");
      _delay_ms(750);
      LCD_clear();
      LCD_displayString((u8 *)"Please turn off");
      LCD_moveCursor(1, 0);
      LCD_displayString((u8 *)"PSU for now...");
      _delay_ms(2000);
      LCD_clear();

      // Setting error to 1
      local_u8Err = 1;
   } else {
      // Setting error to 0
      local_u8Err = 0;
   }
}

void SPSV2_updateScreenPosition(u16 copy_u16PotAdcVal, u8 *copy_u8CursorPos,
                                u8 *copy_u8ScreenPos) {
   // Conditions to change the variables based on the ADC value.
   if (copy_u16PotAdcVal >= 0 && copy_u16PotAdcVal < 170) {
      *copy_u8ScreenPos = SCREEN_1;
      *copy_u8CursorPos =
          0;  // High Voltage output using the buck converter circuit.
   } else if (copy_u16PotAdcVal >= 170 && copy_u16PotAdcVal < 340) {
      *copy_u8ScreenPos = SCREEN_1;
      *copy_u8CursorPos = 1;  // Second function of traditional Voltage output.
   } else if (copy_u16PotAdcVal >= 340 && copy_u16PotAdcVal < 510) {
      *copy_u8ScreenPos = SCREEN_2;
      *copy_u8CursorPos =
          0;  // Third function to turn on lithium battery charging.
   } else if (copy_u16PotAdcVal >= 510 && copy_u16PotAdcVal < 680) {
      *copy_u8ScreenPos = SCREEN_2;
      *copy_u8CursorPos =
          1;  // Fourth function to Measure input signal frequency and duty cycle.
   } else if (copy_u16PotAdcVal >= 680 && copy_u16PotAdcVal < 850) {
      *copy_u8ScreenPos = SCREEN_3;
      *copy_u8CursorPos =
          0;  // Fifth function to Control Fan Speed.
   } else if (copy_u16PotAdcVal >= 850) {
   *copy_u8ScreenPos = SCREEN_3;
   *copy_u8CursorPos =
   1;  // Sixth function to turn off the fan completely.
   }
}
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
